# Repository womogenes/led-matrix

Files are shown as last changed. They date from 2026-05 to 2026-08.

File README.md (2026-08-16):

# LED matrix

Code and 3d print files for my lil LED matrix `=^・ω・^=`

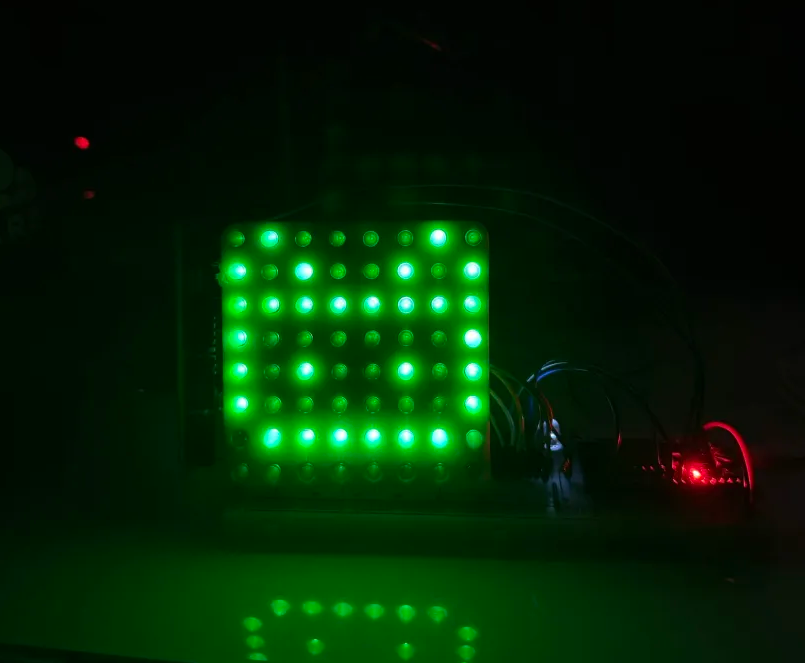
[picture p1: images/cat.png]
Cat on LED matrix


## What is the point

To show that I can make a half-polished LED matrix from scratch using:

- 5 mm LEDs (x64)
- A 3rd printer
- 74HC595 shift registers (x2)
- 200-ohm resistors (x8)
- An ESP32 using five GPIO pins

## Wiring

One 74HC595 drives the row anodes. Its SRCLK and RCLK inputs are tied together.
The other drives the column cathodes and has separate SRCLK and RCLK inputs.

- GPIO32 / yellow → cathode SRCLK
- GPIO26 / blue → cathode RCLK
- GPIO25 / white → anode SRCLK and RCLK tied together
- GPIO33 / green → cathode SER
- GPIO27 / green → anode SER

## What can it do

- Display 8x8 images with bitdepth of 1

## Up and coming features

- Increase bitdepth
- Add video streaming
- Add arcade games

## Notes

```sh
cd src
make flash main/main.c
```

to build and flash the main program. Pass another C file, such as
`main/debug.c`, to build and flash that program instead.

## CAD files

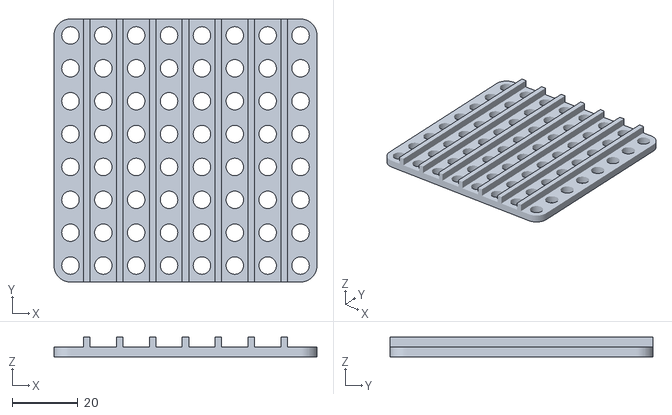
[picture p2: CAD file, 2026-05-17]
hardware/LED V1.2.stl
80.0 x 80.0 x 6.00

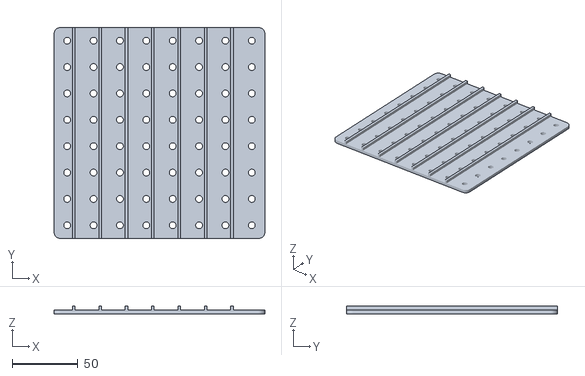
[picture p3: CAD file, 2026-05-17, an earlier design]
hardware/LED V1.1.stl
160.0 x 160.0 x 6.00

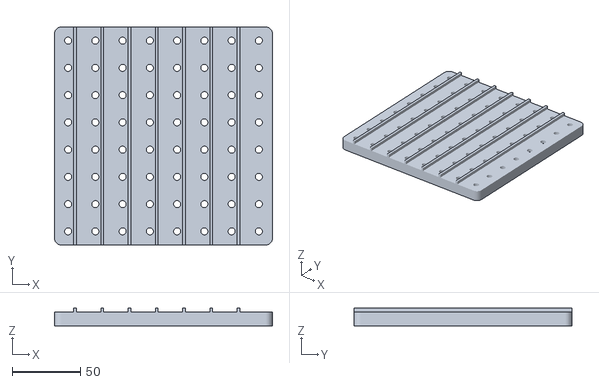
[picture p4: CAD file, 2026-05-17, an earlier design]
hardware/LED V1.stl
160.0 x 160.0 x 13.0

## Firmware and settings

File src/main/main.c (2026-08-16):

/*
  esp-idf yay!
*/

#include <inttypes.h>
#include <stdbool.h>
#include <stdint.h>
#include <stdio.h>
#include <string.h>

#include "driver/gpio.h"
#include "esp_event.h"
#include "esp_http_server.h"
#include "esp_log.h"
#include "esp_rom_sys.h"
#include "esp_system.h"
#include "esp_task_wdt.h"
#include "freertos/FreeRTOS.h"
#include "freertos/task.h"
#include "nvs_flash.h"
#include "protocol_examples_common.h"
#include "sdkconfig.h"
#include "soc/gpio_struct.h"

#define DISPLAY_CORE 1
#define ROW_HOLD_US 1000

static const char *TAG = "led_matrix";

// serial and clock pins for cathodes (columns)
static const int SER_CAT = 33;
static const int SRCLK_CAT = 32; // shift in new input
static const int RCLK_CAT = 26;  // latch to output

// serial and clock pins for anodes (rows)
static const int SER_AN = 27;
static const int CLK_AN = 25;

static uint8_t active_frame[8] = {
  0b00000000,
  0b01000010,
  0b10100101,
  0b11111111,
  0b10000001,
  0b10100101,
  0b10000001,
  0b01111110,
};
static uint8_t pending_frame[8];
static bool pending_frame_ready = false;
static portMUX_TYPE frame_lock = portMUX_INITIALIZER_UNLOCKED;

static inline void digital_write(int pin, int value) {
  if (pin < 32) {
    if (value) {
      GPIO.out_w1ts = 1UL << pin;
    } else {
      GPIO.out_w1tc = 1UL << pin;
    }
  } else {
    const uint32_t mask = 1UL << (pin - 32);
    if (value) {
      GPIO.out1_w1ts.val = mask;
    } else {
      GPIO.out1_w1tc.val = mask;
    }
  }
}

void pulse_pin(int pin) {
  digital_write(pin, 0);
  digital_write(pin, 1);
}

void display_image(uint8_t arr[8]) {
  // Put 0 into first row, 1 for the next 7
  for (int row = 0; row < 8; row++) {
    // Shift in the column
    for (int col = 0; col < 8; col++) {
      digital_write(SER_CAT, (arr[row] & (1 << col)));
      pulse_pin(SRCLK_CAT);
    }
    // pulse_pin(SRCLK_CAT); // TODO: unclear if this is requireed
    pulse_pin(RCLK_CAT);

    // Loop over active row
    digital_write(SER_AN, (row == 7) ? 0 : 1);
    pulse_pin(CLK_AN);

    esp_rom_delay_us(ROW_HOLD_US);
  }

  taskENTER_CRITICAL(&frame_lock);
  if (pending_frame_ready) {
    memcpy(active_frame, pending_frame, sizeof(active_frame));
    pending_frame_ready = false;
  }
  taskEXIT_CRITICAL(&frame_lock);
}

void configure_pin(int pin) {
  gpio_reset_pin(pin);
  gpio_set_direction(pin, GPIO_MODE_OUTPUT);
}

void display_task() {
  // Remove watchdog
  esp_task_wdt_delete(xTaskGetIdleTaskHandleForCore(DISPLAY_CORE));

  while (true)
    display_image(active_frame);
}

static esp_err_t frame_ws_handler(httpd_req_t *req) {
  // Runs on every websocket command
  if (req->method == HTTP_GET) {
    ESP_LOGI(TAG, "WebSocket client connected");
    return ESP_OK;
  }

  uint8_t frame[8];
  httpd_ws_frame_t pkt = {0};
  esp_err_t ret = httpd_ws_recv_frame(req, &pkt, 0);
  if (ret != ESP_OK)
    return ret;

  if (pkt.type != HTTPD_WS_TYPE_BINARY || pkt.len != sizeof(frame)) {
    ESP_LOGW(
      TAG, "Rejected WebSocket frame: type=%d len=%d", pkt.type, pkt.len);
    return ESP_FAIL;
  }

  // Write the 8 bytes to `frame`
  pkt.payload = frame;
  ret = httpd_ws_recv_frame(req, &pkt, sizeof(frame));
  if (ret != ESP_OK)
    return ret;

  // Swap frames with lock
  taskENTER_CRITICAL(&frame_lock);
  memcpy(pending_frame, frame, sizeof(pending_frame));
  pending_frame_ready = true;
  taskEXIT_CRITICAL(&frame_lock);

  return ESP_OK;
}

static httpd_handle_t start_webserver(void) {
  httpd_handle_t server = NULL;
  esp_netif_ip_info_t ip_info;
  httpd_config_t config = HTTPD_DEFAULT_CONFIG();
  config.core_id = 0;

  static const httpd_uri_t frame_ws = {
    .uri = "/frame",
    .method = HTTP_GET,
    .handler = frame_ws_handler,
    .is_websocket = true,
  };

  ESP_ERROR_CHECK(httpd_start(&server, &config));
  ESP_ERROR_CHECK(httpd_register_uri_handler(server, &frame_ws));
  ESP_ERROR_CHECK(esp_netif_get_ip_info(get_example_netif(), &ip_info));
  ESP_LOGI(TAG,
           "WebSocket endpoint ready at ws://" IPSTR "/frame",
           IP2STR(&ip_info.ip));

  return server;
}

void app_main(void) {
  // Fetch credentials + check wifi connection
  ESP_ERROR_CHECK(nvs_flash_init());
  ESP_ERROR_CHECK(esp_netif_init());
  ESP_ERROR_CHECK(esp_event_loop_create_default());
  ESP_ERROR_CHECK(example_connect());
  start_webserver();

  // Reset the pins
  configure_pin(SER_CAT);
  configure_pin(SRCLK_CAT);
  configure_pin(RCLK_CAT);
  configure_pin(SER_AN);
  configure_pin(CLK_AN);

  // Display task on dedicated core 1
  xTaskCreatePinnedToCore(display_task,
                          "display",
                          4096, // bytes allocated to task size
                          NULL,
                          configMAX_PRIORITIES - 1, // priority
                          NULL,
                          DISPLAY_CORE // core ID
  );
}

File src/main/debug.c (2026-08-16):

#include <stdbool.h>
#include <stddef.h>
#include <stdio.h>
#include <string.h>

#include "driver/gpio.h"
#include "driver/uart.h"
#include "driver/uart_vfs.h"
#include "esp_err.h"
#include "freertos/FreeRTOS.h"
#include "sdkconfig.h"

typedef struct {
  char key;
  char name[32];
  gpio_num_t gpio;
  bool level;
} debug_pin_t;

#define MAX_DEBUG_PINS 16
#define COMMAND_LENGTH 96

static debug_pin_t debug_pins[MAX_DEBUG_PINS] = {
  {
    .key = 'j',
    .name = "anode SER (green)",
    .gpio = GPIO_NUM_27,
  },
  {
    .key = 'k',
    .name = "anode CLK (white)",
    .gpio = GPIO_NUM_25,
  },
  {
    .key = 'a',
    .name = "cathode SER (green)",
    .gpio = GPIO_NUM_33,
  },
  {
    .key = 's',
    .name = "cathode SRCLK (yellow)",
    .gpio = GPIO_NUM_32,
  },
  {
    .key = 'd',
    .name = "cathode RCLK (blue)",
    .gpio = GPIO_NUM_26,
  },
};

static size_t debug_pin_count = 5;

static void print_help(void) {
  printf("\nGPIO debug controls:\n");
  for (size_t i = 0; i < debug_pin_count; ++i) {
    printf("  %c  toggle %-27s GPIO %d\n",
           debug_pins[i].key,
           debug_pins[i].name,
           debug_pins[i].gpio);
  }
  printf("  r  reset every output LOW\n");
  printf("  ?  print this help\n");
  printf("\nRuntime configuration (prefix each command with ':'):\n");
  printf("  :map <key> <gpio> <name>\n");
  printf("  :unmap <key>\n");
  printf("  :list\n");
  printf("  :reset\n\n");
}

static void reset_outputs(void) {
  for (size_t i = 0; i < debug_pin_count; ++i) {
    debug_pins[i].level = false;
    ESP_ERROR_CHECK(gpio_set_level(debug_pins[i].gpio, 0));
  }
  printf("all debug outputs LOW\n");
}

static void configure_output(gpio_num_t gpio) {
  ESP_ERROR_CHECK(gpio_reset_pin(gpio));
  ESP_ERROR_CHECK(gpio_set_direction(gpio, GPIO_MODE_OUTPUT));
  ESP_ERROR_CHECK(gpio_set_level(gpio, 0));
}

static void configure_outputs(void) {
  for (size_t i = 0; i < debug_pin_count; ++i) {
    configure_output(debug_pins[i].gpio);
  }
  reset_outputs();
}

static void configure_console_uart(void) {
  const uart_port_t uart = (uart_port_t)CONFIG_ESP_CONSOLE_UART_NUM;

  if (!uart_is_driver_installed(uart)) {
    ESP_ERROR_CHECK(uart_driver_install(uart, 256, 0, 0, NULL, 0));
  }

  uart_vfs_dev_use_driver(uart);
  setvbuf(stdin, NULL, _IONBF, 0);
  setvbuf(stdout, NULL, _IONBF, 0);
}

static int find_key(char key) {
  for (size_t i = 0; i < debug_pin_count; ++i) {
    if (debug_pins[i].key == key) {
      return (int)i;
    }
  }
  return -1;
}

static bool gpio_is_available(int gpio, int current_index) {
  if (!GPIO_IS_VALID_OUTPUT_GPIO(gpio) || gpio == 1 || gpio == 3 ||
      (gpio >= 6 && gpio <= 11)) {
    return false;
  }

  for (size_t i = 0; i < debug_pin_count; ++i) {
    if ((int)i != current_index && debug_pins[i].gpio == gpio) {
      return false;
    }
  }
  return true;
}

static bool key_is_available(char key) {
  return key >= '!' && key <= '~' && strchr("r?:q", key) == NULL;
}

static void map_pin(char key, int gpio, const char *name) {
  if (key >= 'A' && key <= 'Z') {
    key += 'a' - 'A';
  }

  const int index = find_key(key);
  if (!key_is_available(key)) {
    printf("ERR key '%c' is reserved or invalid\n", key);
    return;
  }
  if (!gpio_is_available(gpio, index)) {
    printf("ERR GPIO %d is unavailable, unsafe, or already mapped\n", gpio);
    return;
  }
  if (index < 0 && debug_pin_count == MAX_DEBUG_PINS) {
    printf("ERR mapping table is full\n");
    return;
  }

  debug_pin_t *pin =
    index < 0 ? &debug_pins[debug_pin_count++] : &debug_pins[index];
  if (index >= 0) {
    ESP_ERROR_CHECK(gpio_set_level(pin->gpio, 0));
    ESP_ERROR_CHECK(gpio_reset_pin(pin->gpio));
  }

  pin->key = key;
  pin->gpio = (gpio_num_t)gpio;
  pin->level = false;
  snprintf(pin->name, sizeof(pin->name), "%s", name);
  configure_output(pin->gpio);
  printf("OK mapped %c to GPIO %d (%s)\n", pin->key, pin->gpio, pin->name);
}

static void unmap_pin(char key) {
  if (key >= 'A' && key <= 'Z') {
    key += 'a' - 'A';
  }

  const int index = find_key(key);
  if (index < 0) {
    printf("ERR key '%c' is not mapped\n", key);
    return;
  }

  ESP_ERROR_CHECK(gpio_set_level(debug_pins[index].gpio, 0));
  ESP_ERROR_CHECK(gpio_reset_pin(debug_pins[index].gpio));
  memmove(&debug_pins[index],
          &debug_pins[index + 1],
          (debug_pin_count - (size_t)index - 1) * sizeof(debug_pins[0]));
  --debug_pin_count;
  printf("OK unmapped %c\n", key);
}

static void process_command(char *command) {
  char key;
  int gpio;
  char name[sizeof(debug_pins[0].name)];

  if (sscanf(command, "map %c %d %31[^\r\n]", &key, &gpio, name) == 3) {
    map_pin(key, gpio, name);
  } else if (sscanf(command, "unmap %c", &key) == 1) {
    unmap_pin(key);
  } else if (strcmp(command, "list") == 0 || strcmp(command, "help") == 0) {
    print_help();
  } else if (strcmp(command, "reset") == 0) {
    reset_outputs();
  } else {
    printf("ERR unknown command; use :help\n");
  }
}

static void read_command(void) {
  char command[COMMAND_LENGTH];
  size_t length = 0;
  bool overflow = false;

  while (true) {
    const int input = getchar();
    if (input < 0) {
      continue;
    }
    if (input == '\r') {
      continue;
    }
    if (input == '\n') {
      break;
    }
    if (length + 1 < sizeof(command)) {
      command[length++] = (char)input;
    } else {
      overflow = true;
    }
  }

  if (overflow) {
    printf("ERR command is too long\n");
    return;
  }
  command[length] = '\0';
  process_command(command);
}

static bool toggle_pin_for_key(char key) {
  const int index = find_key(key);
  if (index < 0) {
    return false;
  }

  debug_pin_t *pin = &debug_pins[index];
  pin->level = !pin->level;
  ESP_ERROR_CHECK(gpio_set_level(pin->gpio, pin->level));
  printf(
    "%s (GPIO %d) -> %s\n", pin->name, pin->gpio, pin->level ? "HIGH" : "LOW");
  return true;
}

void app_main(void) {
  configure_console_uart();
  configure_outputs();
  print_help();

  while (true) {
    const int input = getchar();
    if (input < 0) {
      continue;
    }

    char key = (char)input;
    if (key >= 'A' && key <= 'Z') {
      key += 'a' - 'A';
    }

    if (key == ':') {
      read_command();
    } else if (key == 'r') {
      reset_outputs();
    } else if (key == '?') {
      print_help();
    } else {
      toggle_pin_for_key(key);
    }
  }
}

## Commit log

2026-05-17 Switch to esp-idf
    [LED V1.1.stl, LED V1.2.stl, LED V1.stl]
2026-05-17 Burn one core on GPIO
    [main.c]
